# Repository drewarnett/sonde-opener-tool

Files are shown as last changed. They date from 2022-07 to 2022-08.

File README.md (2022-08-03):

# sonde-opener-tool

Tools(s) to open radiosondes.  Mechanical tools.

Locally, folks have been recovering NWS radiosondes.  Specifically,
[Vaisala RS41-SGP](https://www.vaisala.com/en/products/weather-environmental-sensors/upper-air-radiosondes-rs41) sondes.  (And reprogramming for a nearby
amateur radio band and re-flying them.)

These are held together with a couple of plastic clips.  Sure, these can be
pried open, but it seemed like an interesting design problem to come up with a
clip release tool.

The lower clip was easy, and works great as a 3D printed tool.  The clip
releases with a satisfying click.  Design can be found [HERE](lower).

The upper clip is more stout.  A two stage procedure seems to work well with
3D printed tools.  No satisfying click unfortunately.  Design can be found
[HERE](upper).

Drew Arnett, n7da

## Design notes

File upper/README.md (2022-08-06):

# upper-tools

A pair of tools for removing the upper clip from a Vaisala RS41-SGP radiosonde.

* [upper-stage-1-tool.pdf](upper-stage-1-tool.pdf)
* [upper-stage-2-tool.pdf](upper-stage-2-tool.pdf)

## Instructions for use

1.  Press the pronged end of the stage 1 tool into the upper clip.  This will
    at least partially disengage the clip.

2.  If needed, press the pronged end of the stage 2 tool into the upper clip
    to disengage the clip entirely.

    Note:  the upper clip extends to the back wall of the rear clamshell.  Step
           1 works well enough holding in hand.  However, step 2 requires
           holding the front polystyrene clamshell so the upper clip can
           disengage fully.  It is easier than it sounds.

## Instructions for printing

I printed on a Prusa with PLA filament using a 0.2 mm layer height and solid
fill.  I used the default 2 layer outer shell for the stage 1 tool and a 3
layer outer shell for the stage 2 tool.  The tool isn't too fussy, so a variety
of printing options will likely work fine.  2 layer outer shell should be fine
for both, but the stage 1 tool has more stress and might benefit more from more
outer shell.

An optional thumbsaver can be printed for the stage 1 tool.  Insert the end of
the tool opposite the prongs into the slot in the thumbsaver.

## Design notes

Measurements were made from a sample RS41-SGP radiosonde.

A bit of sketching and designing with the dimensions was done on a piece of
paper.  Then the parts were designed in FreeCAD.

Drew Arnett, n7da

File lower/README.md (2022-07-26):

# lower-tool

A tool for removing the lower clip from a Vaisala RS41-SGP radiosonde.

## Instructions for use

1.  Press the pronged end of the tool into the lower clip.  A click should be
    heard as the clip releases.

2.  Use the other end of the tool to press the clip out enough to easily grasp
    and remove from the back of the sonde.

## Instructions for printing

I printed on a Prusa with PLA filament using a 0.2 mm layer height, default 2
layer outer shell, and solid fill.  The tool isn't too fussy, so a variety of
printing options will likely work fine.

## Design notes

Measurements were made from a sample RS41-SGP radiosonde.

A outline was drawn with LibreCAD and saved as a .dxf file.

A two line OpenSCAD file was used to import the .dxf outline and extrude it to
the correct thickness.  Then the design was exported as a .stl model for
printing.

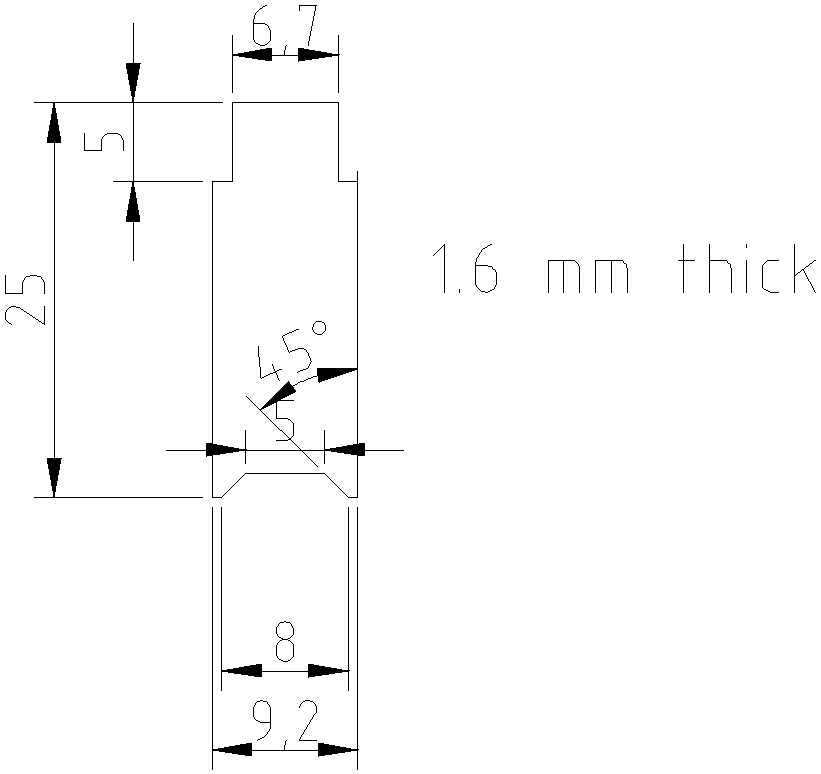
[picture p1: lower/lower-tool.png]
dimensioned drawing


Drew Arnett, n7da

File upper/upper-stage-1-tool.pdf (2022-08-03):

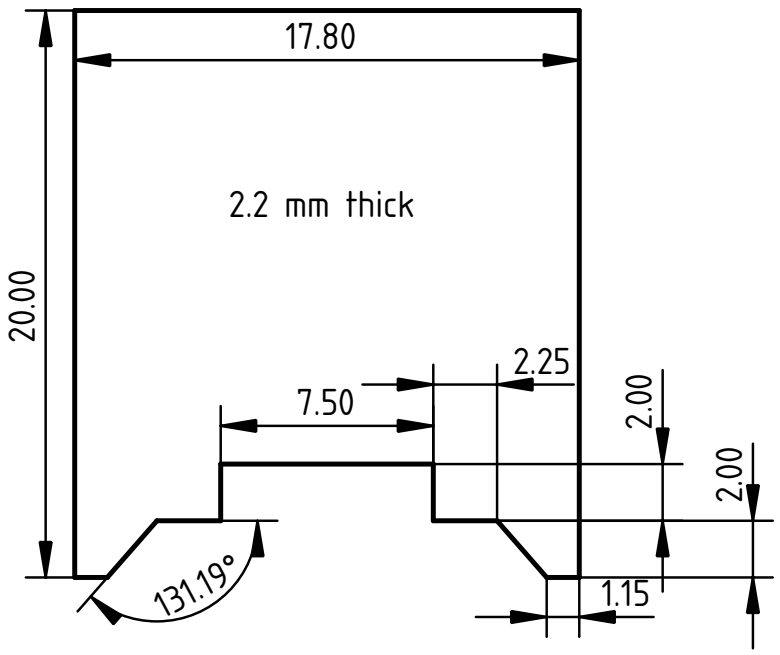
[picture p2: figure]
2.2 mm thick

upper-stage-1-tool

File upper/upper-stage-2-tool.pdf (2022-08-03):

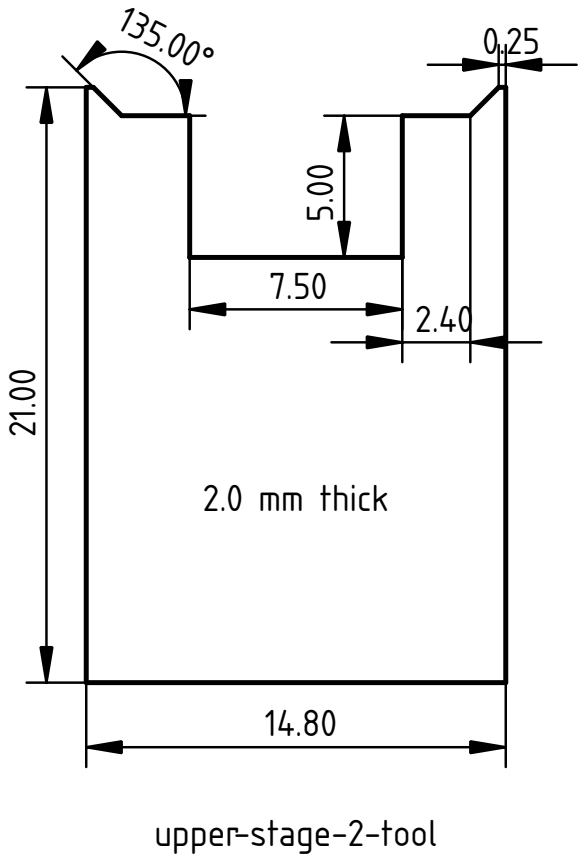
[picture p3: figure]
2.0 mm thick; upper-stage-2-tool

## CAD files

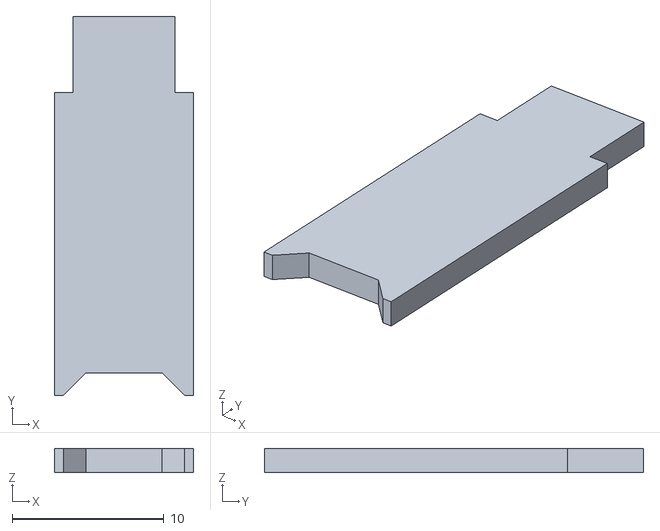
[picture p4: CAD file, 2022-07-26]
lower/lower-tool.stl
9.20 x 25.0 x 1.60

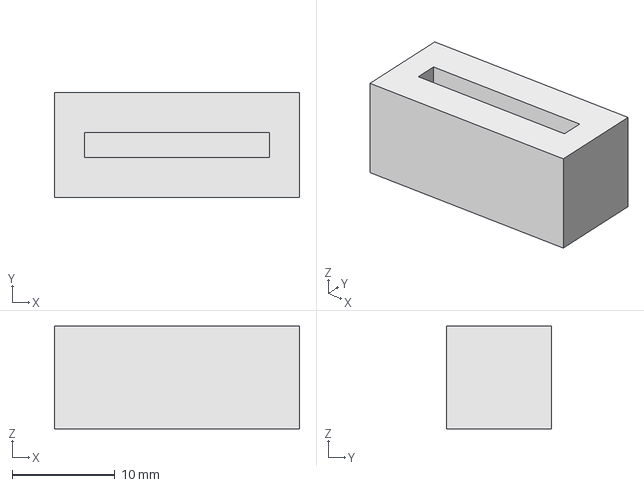
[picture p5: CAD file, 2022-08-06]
upper/upper-stage-1-tool-thumbsaver.FCStd
23.8 x 10.2 x 10.0 mm

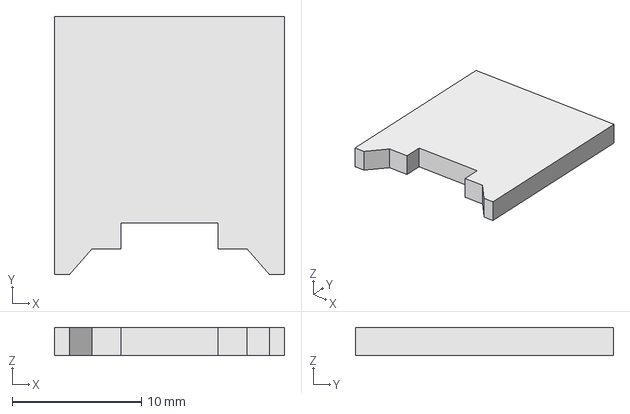
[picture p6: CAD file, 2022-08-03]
upper/upper-stage-1-tool.FCStd
17.8 x 20.0 x 2.20 mm

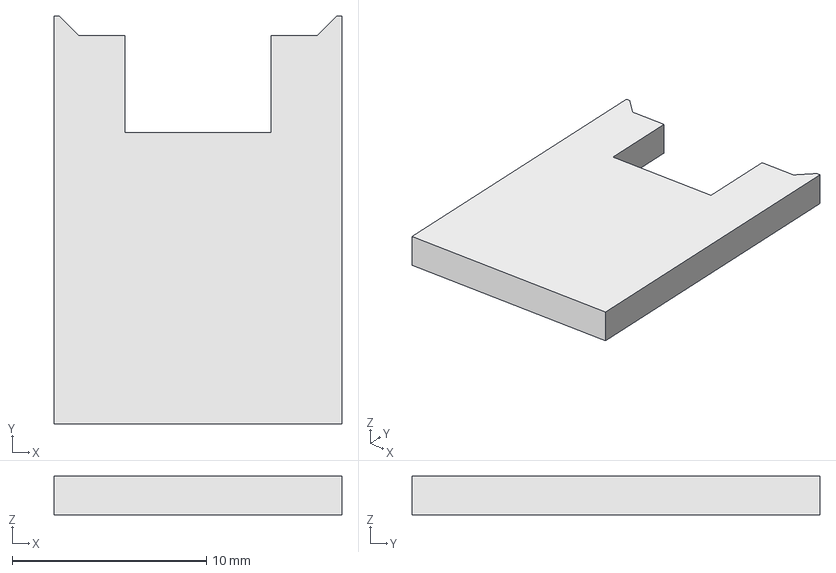
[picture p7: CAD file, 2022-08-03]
upper/upper-stage-2-tool.FCStd
14.8 x 21.0 x 2.00 mm

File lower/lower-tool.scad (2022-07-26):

linear_extrude(1.6)
import("lower-tool.dxf", "outline");

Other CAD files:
lower/lower-tool.dxf
upper/upper-stage-1-tool-thumbsaver.stl
upper/upper-stage-1-tool.stl
upper/upper-stage-2-tool.stl

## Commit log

2022-07-26 add main README and lower-tool
    [lower-tool.dxf, lower-tool.scad, lower-tool.stl]
2022-08-03 add upper stage 2 tool
    [upper-stage-2-tool.FCStd, upper-stage-2-tool.stl]
2022-08-03 add upper stage 1 tool
    [upper-stage-1-tool.FCStd, upper-stage-1-tool.stl]
2022-08-06 add upper stage 1 tool thumbsaver
    [upper-stage-1-tool-thumbsaver.FCStd, upper-stage-1-tool-thumbsaver.stl]
